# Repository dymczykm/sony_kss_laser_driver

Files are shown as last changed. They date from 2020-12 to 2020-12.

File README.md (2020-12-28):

# Sony KSS laser pickup driver

This board is used to drive the KSS-family pickups (KSS-16x, KSS-220 etc.) with a circuit very similar to one used by various kinds of mobile and home players, which all used the CXA1081 IC. Personally, I've used this circuit to measure/adjust the laser diode current and to measure the light emission (using a Leader LPM-8000 meter). A separate circuit like this one makes it much easier to handle the pickup compared to working within cramped Discman or car audio players.

The circuit is pretty much a copy of the Alpine 7909 design, but very closely resembles Discmans (such as D-33) from that era. The only difference I've noticed is the resistor for the `VR` line - it's 0-ohm in 7909, but 91-ohm in some of the Discman implementations.

The circuit is tested and worked fine on several Sony pickups without burning any of them :) Still, you use it at your own risk.

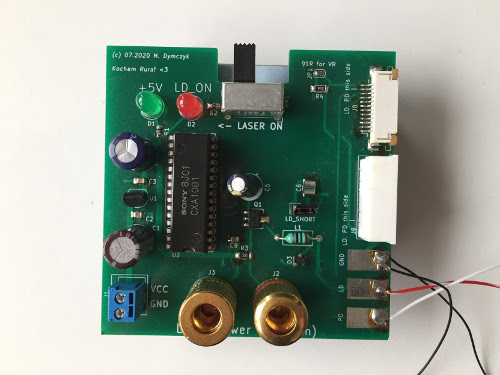
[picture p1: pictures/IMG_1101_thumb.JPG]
3D render


## Potentially compatible devices/pickups

### Sony Discmans
- KSS-220A (D-11, D-22, D-33, D-99, D-800K, D-802K)
- KSS-162A (D-4, D-12, D-20, D-T20, D-30, D-34, D-40, D-55T, D-90, D-100)

### Car audio
- Alpine 7909 (KSS-163A)
- Sony CDX-5080 CDX-7580 CDX-R77 CDX-R79 (KSS-168A)
- Blaupunkt CD42 family
- Blaupunkt New York SCD08 (KSS-164A), BMW Bavaria ELECTRONIC CD (II)

## Connections

### Power supply
Connect to `J1` a stable power source within the range acceptable by `78L05` used in the circuit.

### Laser pickup
You can use either of the 3 connections:
- 1mm pitch FFC connector,
- 1.25mm pitch FFC conector,
- solder pads (`PD` - monitor diode, `LD` - laser diode, `GND` - ground); please mind the ESD measures.

The `LD_SHORT` jumper shorts out the laser diode. Remove the jumper once your pickup is fully connected.

### Switching on the laser diode

Use the `SW1` switch to turn on the diode. After turning it on, do not look directly into it lens.

### Measuring laser diode current

You can measure the laser current on the `J2`/`J3` banana jacks as a voltage across a 10-ohm resistor.

## CXA1081 symbol/footprint

You can find it in [my library](https://github.com/dymczykm/marcin_kicad_library).

CXA1081 has a Samsung equivalent (KA9201) and its [datasheet is hosted by console5.com](https://console5.com/techwiki/images/a/a1/KA9201.pdf).

## Component list

I've sourced CXA1081 SDIP from ebay (I took a used one to be sure it's not a counterfeit).

Most other components are listed in the [CSV file](digikey_bom.csv). Please note that it does not contain components I had already at hand, so double check it against the schematic.

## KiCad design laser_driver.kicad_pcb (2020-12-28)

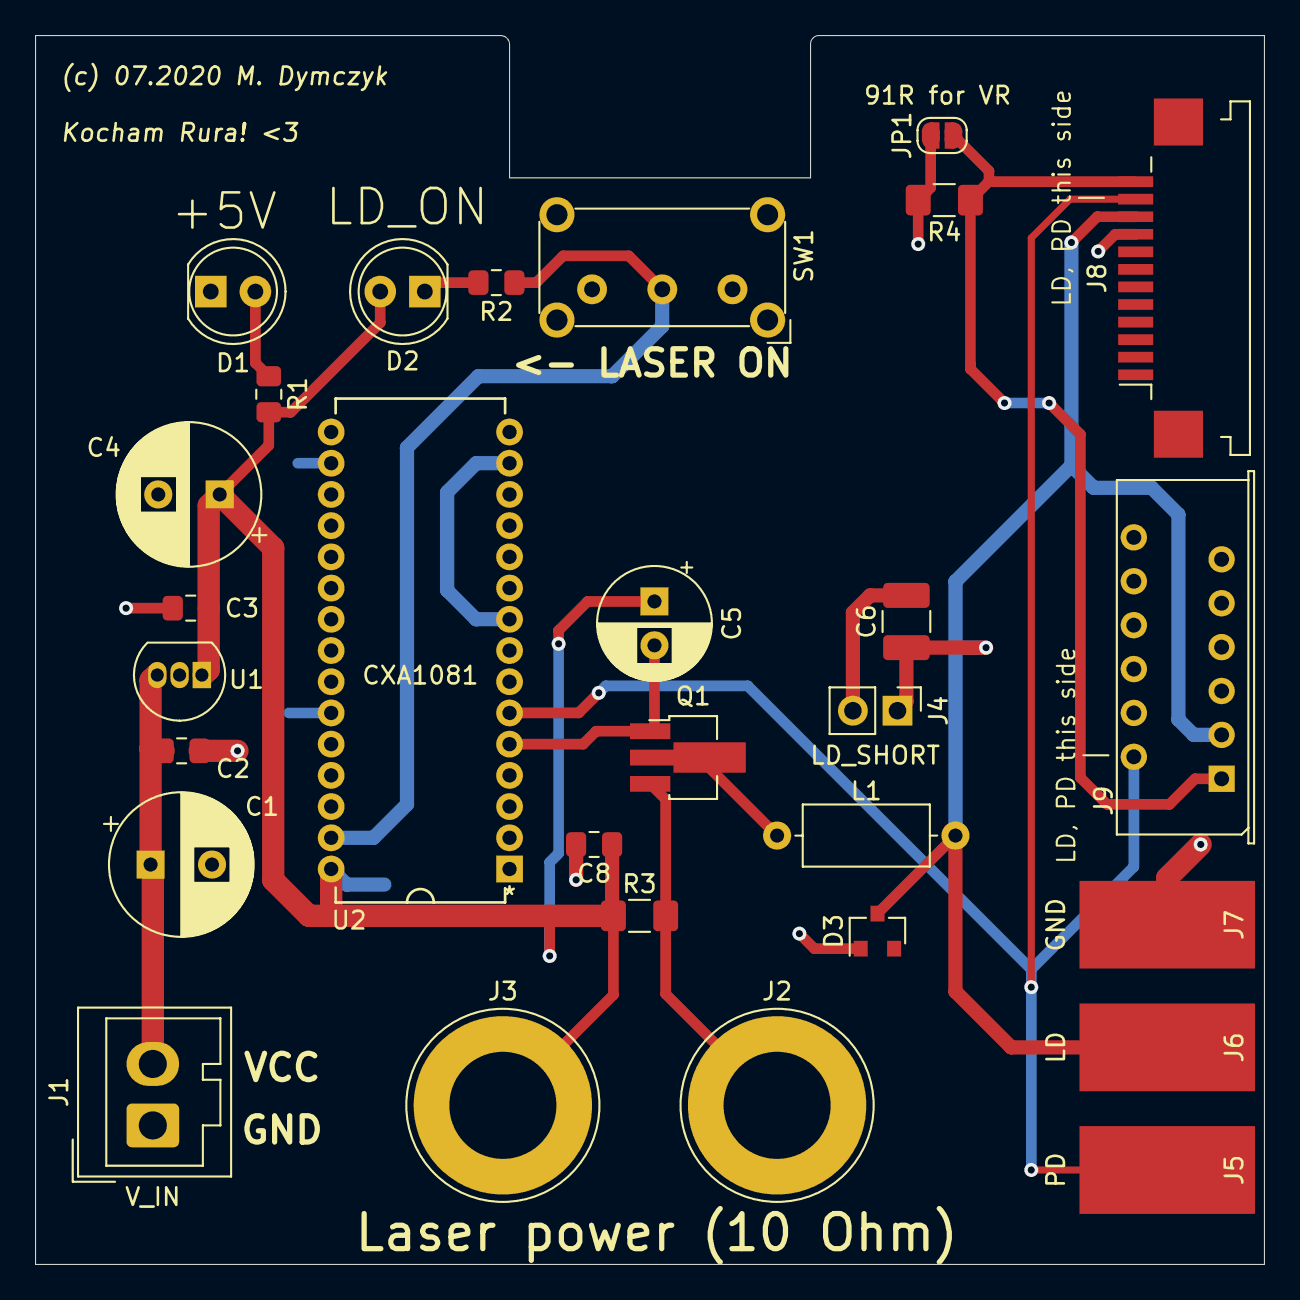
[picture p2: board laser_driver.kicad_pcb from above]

Board: 2 copper layers, 70.0 x 70.0 mm, 30 parts (1 on the bottom side), 13 nets.

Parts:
C1, C4: 100u; CP_Radial_D8.0mm_P3.50mm
C2, C3, C7, C8: 100n; C_0805_2012Metric_Pad1.15x1.40mm_HandSolder
C5: 47u/4v; CP_Radial_D6.3mm_P2.50mm
C6: 1u/10; C_1210_3225Metric_Pad1.42x2.65mm_HandSolder
D1: +5V; LED_D5.0mm
D2: LD_ON; LED_D5.0mm
D3: M1MA151KT1G; D_SOT-23_ANK
J1: V_IN; Wago_734-132_1x02_P3.50mm_Vertical
J2: Laser; Banana_Jack_1Pin
J3: Power; Banana_Jack_1Pin
J4: LD_SHORT; PinHeader_1x02_P2.54mm_Vertical
J5: PD; SolderWirePad_1x01_SMD_5x10mm
J6: LD; SolderWirePad_1x01_SMD_5x10mm
J7: GND; SolderWirePad_1x01_SMD_5x10mm
J8: 1mm; Molex_0522071233
J9: 1.25mm; Molex_0039532124
JP1: VR; SolderJumper-2_P1.3mm_Open_RoundedPad1.0x1.5mm
L1: 10u; L_Axial_L7.0mm_D3.3mm_P10.16mm_Horizontal_Fastron_MICC
Q1: Q_PNP_BCE; SOT-89-3_Handsoldering
R1, R2: 220; R_0805_2012Metric_Pad1.15x1.40mm_HandSolder
R3: 10 0.1%; R_1206_3216Metric_Pad1.42x1.75mm_HandSolder
R4: 91; R_1206_3216Metric_Pad1.42x1.75mm_HandSolder
SW1: SW_SPDT; SW_E-Switch_EG1224_SPDT_Angled
U1: L78L05_TO92; TO-92_Inline
U2: CXA1081; SDIP30

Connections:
+5V: C3.1, C4.1, C5.1, C7.2, C8.1, D2.2, J3.1, R1.2, R3.1, U1.1, U2.30
GND: C1.2, C2.2, C3.2, C4.2, C6.2, C7.1, C8.2, D1.1, D3.2, J1.1, J4.2, J7.1, J8.9, J9.4, JP1.1, R4.2, SW1.3, U1.2, U2.17, U2.25
unnamed: C1.1, C2.1, J1.2, U1.3
unnamed: C5.2, Q1.1, U2.5
unnamed: C6.1, D3.1, J4.1, J6.1, J8.10, J9.3, L1.2
unnamed: D1.2, R1.1
unnamed: D2.1, R2.2
unnamed: J2.1, Q1.3, R3.2
unnamed: J5.1, J8.11, J9.2, U2.6
unnamed: J8.12, J9.1, JP1.2, R4.1
unnamed: L1.1, Q1.2
unnamed: R2.1, SW1.2, U2.29
unnamed: U2.9, U2.14

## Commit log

2020-12-28 Add files and the readme.
    [laser_driver.kicad_pcb, laser_driver.sch]
2020-12-28 Add a note about the switch.

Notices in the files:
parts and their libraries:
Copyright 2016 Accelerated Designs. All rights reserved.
